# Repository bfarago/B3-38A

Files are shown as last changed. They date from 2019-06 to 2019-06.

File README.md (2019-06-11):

# B3-38A
B3-38A or V3-38A Russian Millivoltmeter

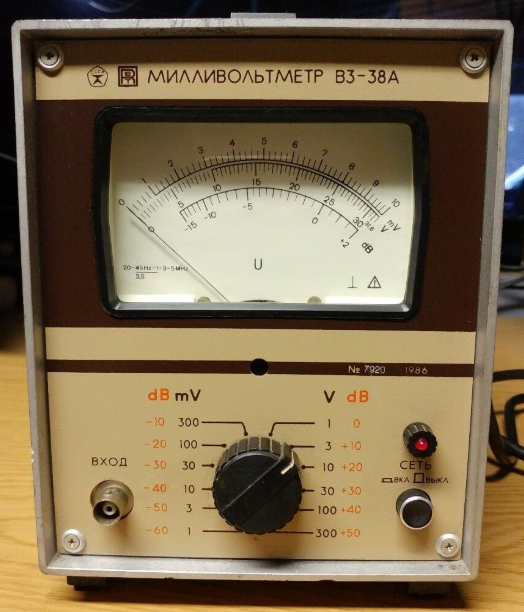
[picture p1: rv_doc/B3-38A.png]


REVERSE ENGINEERING
-------------------
This repository contains all the collected informations regarding the old russian millivoltmeter instrument. The goal to collect datasheets, schematics, etc.

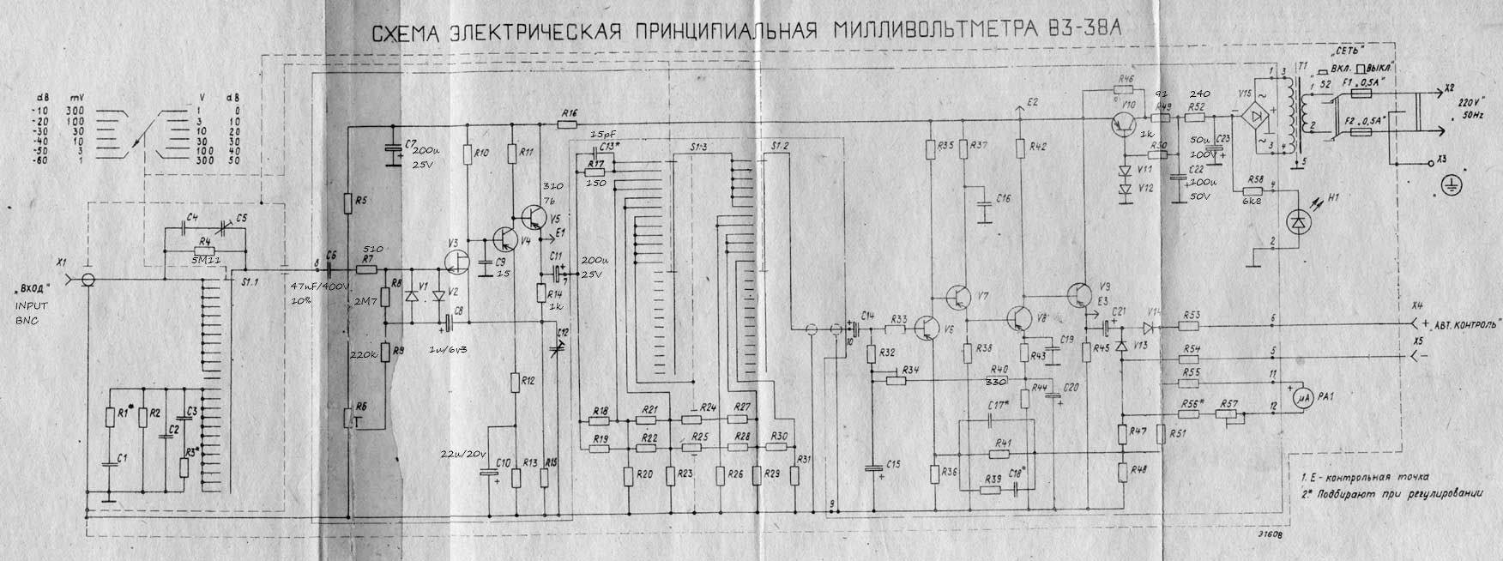
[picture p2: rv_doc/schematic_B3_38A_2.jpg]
Schematic


[BOM](rv_doc/bom.md), [Service Manual](rv_doc/B3-38A.pdf)

Technical characteristics
-------------------------
Millivoltmeter V3-38A (V3 38A, V338A, b3-38a, b338a, b3 38a)

Designed to measure the rms AC voltage sine wave of 0.1 mV to 300 V in the frequency range from 20 Hz to 5 MHz.
The span value of 1 mV, 3mV, 10mV, 30mV, 100mV, 300mV, 1V, 3V, 10V, 30V, 100V and 300V
The basic error of ± 2,5%

Millivoltmeter V3-38A is designed to measure the rms AC voltage sine wave of 0.1 mV to 300 V in the frequency range from 20 Hz to 5 MHz.
The operating conditions of use of the instrument Millivoltmeter V3-38A: ambient temperature from 10 ° to 35 ° C;
relative humidity. air 80% at 25 ° C, atmospheric pressure from 86 to 106 kPa (650 to 800 mm Hg. st.) mains (220 ± 22), frequency (50 ± 0,5) Hz .
Technical Data is a
Measurement range of the instrument voltages from 300V to 100mkV overlapping ranges with upper limits of 1 mV, 3mV, 10mV, 30mV, 100mV, 300mV, 1V, 3V, 10V, 30V, 100V and 300V. Instrument measures the voltage in the frequency range from 20 Hz to 5 MHz .
The range of frequencies of the device Millivoltmeter V3-38A has a working range of frequencies:
I from 45 Hz to 1 MHz (on);
II from 20 to 45 Hz (except);
III St.. 1 to 3 MHz (on);
IV St.. 3 to 5 MHz (inclusive).
Frequency of calibration of 1 kHz. Primary instrument error, expressed as a percentage of the upper limit established by sub-band measurements, no more than ± 2,5%.
Instrument error Millivoltmeter V3-38A in the working frequency regions, expressed as a percentage of the upper limit of the established sub-band, and the change of readings within the operating frequency ranges with respect to the frequency of calibration readings in percent, do not exceed the values shown in Table. 1.

Table 1: The limits of permissible errors (beyond the assumed changes of reading),%

| Subranges | I.: 45Hz- 1 MHz | II.: 20 - 45 Hz | III.:  1 - 3 MHz | IV.: 3 - 5 MHz |
| --- | --- | --- | --- | --- |
| 1 mV-300mV | ± 2,5 % | ± 4,0 (± 4,0) % | ± 4,0 (± 4,0) % | ± 6,0 (± 6,0) % |
| 1V-300V | ± 2,5 % | ± 4,0 (± 4,0) % | ± 6,0 (± 6,0) % | ± 6,0 (± 6,0) % |

Change readings, caused by changes in temperature. Ambient air from the normal to any temperature within the operating temperature range does not exceed the basic error for every 10 ° C change in temperature.
Change readings Millivoltmeter V3-38A, expressed as a percentage of the upper limit established by sub-band, rejecting the shape of the measured voltage from the sinusoidal (THD less than 20%) is less than half the value of the harmonic content in percent.
The deviation of the index from scratch, due to the intrinsic noise does not exceed 5% of the upper limit established by sub-band measurements with closed-circuit input.
The device retains its specifications within the rules, if its input DC voltage is not more than 250-V
Response time the device is less than 4 seconds.
Millivoltmeter V3-38A save tons of basic error handling five times after exposure to stress, but not more than 600 V.
Active impedance device, measured at a frequency of 45 Hz, less than 5 megohms at subbands upper limits 1-300mV and at least 4 Mohms subbands upper limits in 1-300
Input capacitance unit is not more than 25 pF subbands upper limits of 1-300 mV and not more than 15 pF subbands upper limits of 1-300 W.
The capacity of each of the connecting cable is not more than 80 pF. Warm-up time 15 min. Millivoltmeter V3-38A retains its specifications when powered from the mains AC voltage (220 ± 22) V (50 ± 0,5) Hz.
The power consumed by the network at a nominal voltage not exceeding 6 VA. Device allows continuous operation in the working conditions for 8 hours

Unit weight Millivoltmeter V3-38A or less than 3.2 kg.

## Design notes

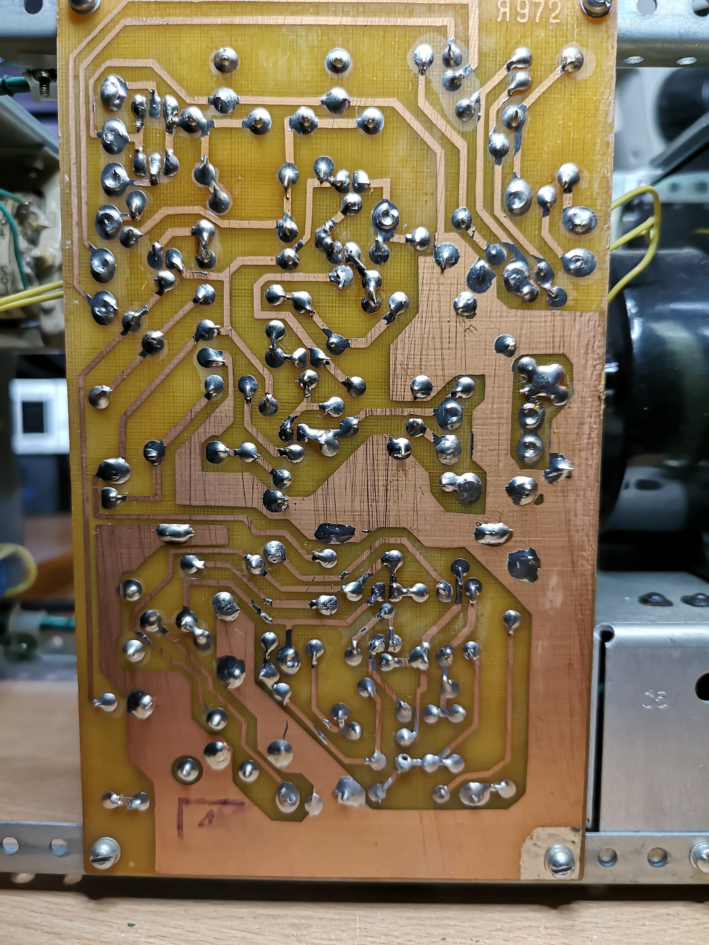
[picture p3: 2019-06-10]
rv_doc/pcb_b_JA972.jpg

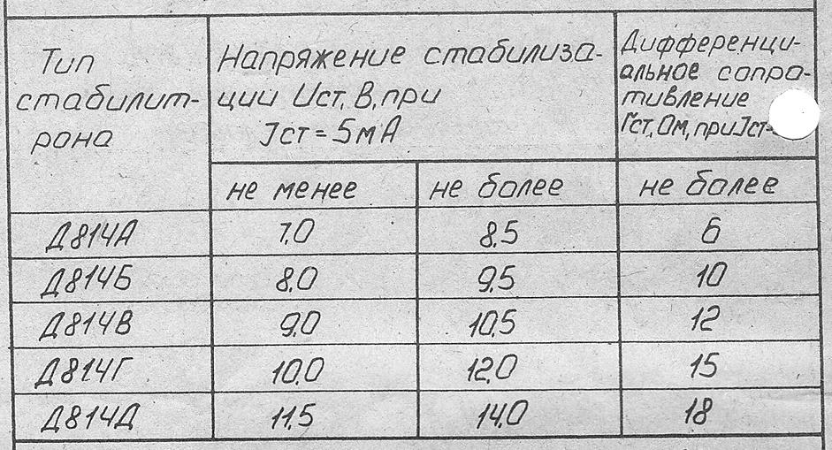
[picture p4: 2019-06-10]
rv_doc/zener_D814D.png

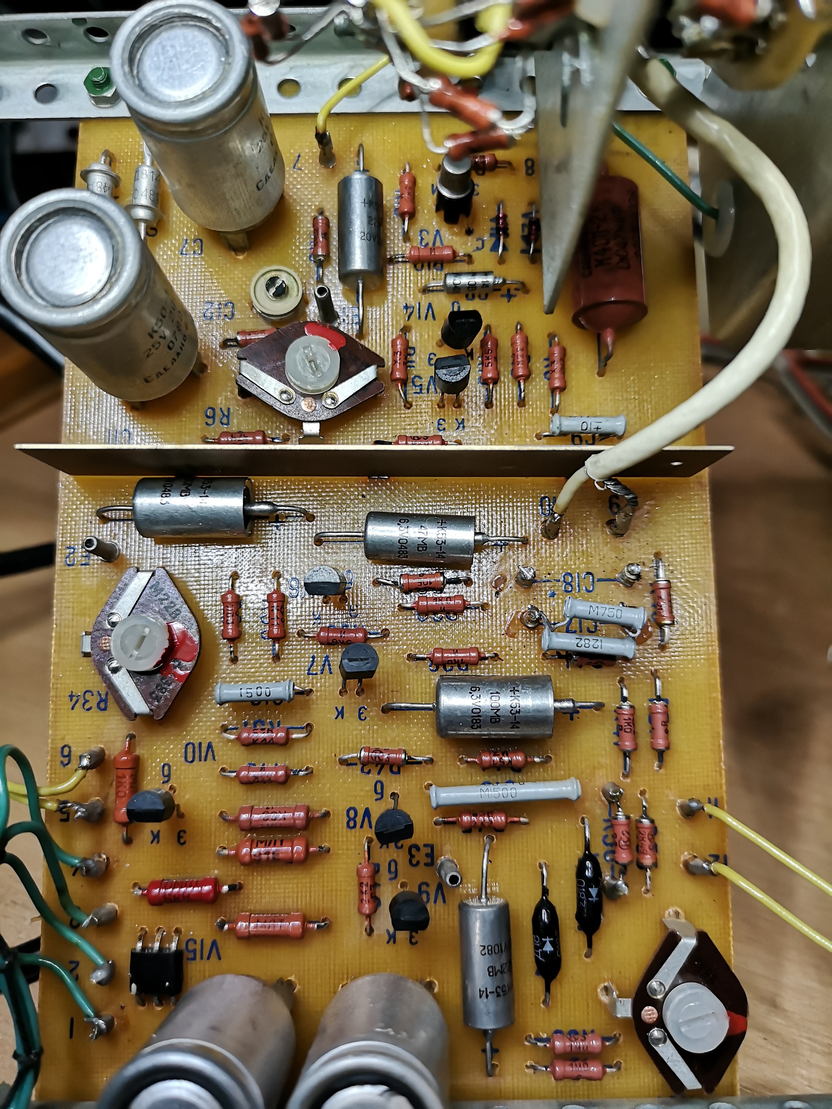
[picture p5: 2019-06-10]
rv_doc/pcb_p_JA972.jpg

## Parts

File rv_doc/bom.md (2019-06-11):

Bill of materials

| Pos | Description | Param |
| --- | --- | --- |
| C1 | KT-1-M1500-150 nF±10%-3 | 150nF ±10% |
| C2 | CrM-3-500B-r-2700n | 2700nF ±10% 500V |
| C3 | Cm-3-500B-r-l600 nF±5% | 1600nF ±5% 500V |
| C4 | KA-26-M75-3.9 nF ±10% 3 | 3,9nF ±10% |
| C5 | KF1K-MH-2/7 nF | 2nF |
| C6 | K40Í1-26 0.047 mkF ±I0% | 47nF ±10% |
| C7 | K50-12-25 B - 200 mkF | 200uF 25V |
| C8 | K53-14-6.3 B-4.7mkF±20% | 4,7uF ±20% 6,3V |
| C9 | KT-1-M47-15 nO ± 5% -3 | 15nF ±5% |
| C10 | K53-14-20 B 22 uMF±20% | 22uF ±20% 20V |
| C11 | K50-12-25 B 200 mkF | 200uF 25V |
| C12 | KT4-23 5/20 | 5nF 20V |
| C13* | KT-1M47-15 15nF l0%-3(0..27 nF) | 15nF |
| C14 | K53-14-6.3 B-47 mkF ±20%  | 47uF 6,3V ±20% |
| C15 | K53-14-6.3 B-100 ukF±20% | 100uF 6,3V ±20% |
| C16 | K10-7B-H30 1500 nF±20% | 1500nF 7V |
| C17* | KT-1-Ml 500-270 nF ±10% -3 (150..270 nF) | 270nF |
| C18* | KT-1-M47-27 nF ±10% -3 (0..47nF)| 27nF  |
| C19 | KT-l-M 1500-560 nF ±l0%-3 | 560nF |
| C20 | K53-I4-6.3 B-100 mkF±20% | 100uF 6,3V |
| C21 | K53-14-20 B-22 mkF±20% | 22uF 20V |
| C22 | K50-12-50 B-100 mkF | 100uF 50V |
| C23 | K50-12-100 B-50 mkO | 50uF 100V |

| Pos | Description | Param |
| --- | --- | --- |
| V1,2 | KD 522 B | 1N4148 |
| V3 | [Kp103L](kp103l.pdf) | p-jFET |
| V4,5,6,7 | KT 3107 B | pnp |
| V9 | KT 3107 A | pnp |
| V10 | KT 3107 B | pnp |
| V11,12 | D 814 D | zener 12V |
| V13,14 |  | diode |

| Pos | Description | Param |
| --- | --- | --- |
| R1* | MJlT-0,25-7,5 kOm±10% | 5.6-27 kOhm |
| R2 | C2-29B-0.25-5,ll kOhm±0.25% — 1,0-B | 5.11 kOhm |
| R3 | 02-10-0,25-21,8 Ohm±1%(20..22,9 Ohm) | 21,8 Ohm |
| R4 | C2-29B-1-5,11 MOhm ±0.25%- 5,0 -5 | 5,11 MOhm |
| R5 | MJ1T-025-47kOhm ±10% | 47kOhm |
| R6 | Gri3^U-33kOhm-1 | 33kOhm |

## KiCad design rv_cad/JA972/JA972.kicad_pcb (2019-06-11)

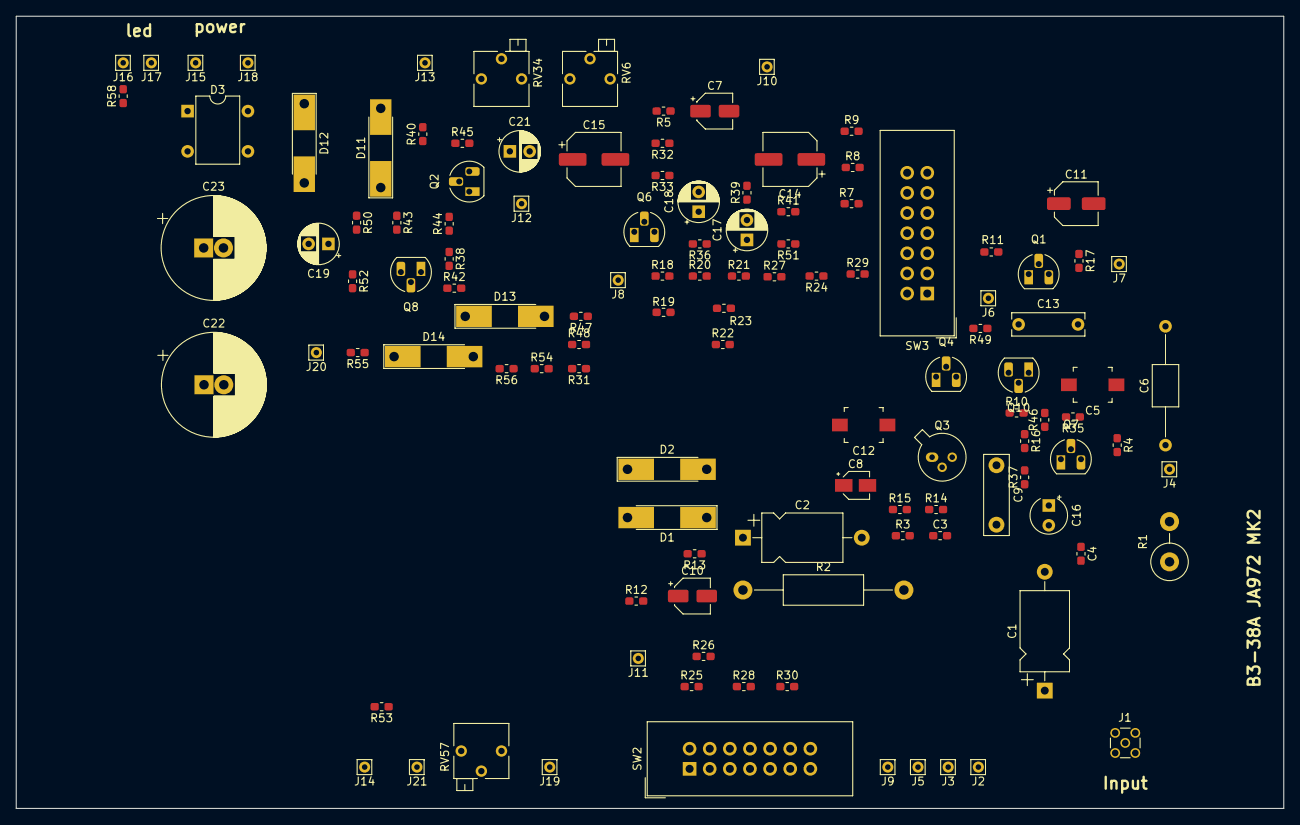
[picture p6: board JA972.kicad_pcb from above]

Board: 2 copper layers, 160.0 x 100.0 mm, 118 parts (0 on the bottom side), 61 nets, no tracks yet.

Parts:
C1: 1600 500V 5%; CP_Axial_L10.0mm_D6.0mm_P15.00mm_Horizontal
C2: 2700 500V 5%; CP_Axial_L10.0mm_D6.0mm_P15.00mm_Horizontal
C3: 150 10%; C_0603_1608Metric_Pad1.05x0.95mm_HandSolder
C4: 2p2; C_0603_1608Metric_Pad1.05x0.95mm_HandSolder
C5: 2/7; C_Trimmer_Murata_TZB4-B
C6: 0,047uF/400V/10%; C_Axial_L5.1mm_D3.1mm_P15.00mm_Horizontal
C7: 200u/25V; CP_Elec_4x5.4
C8: 1u/6v3; CP_Elec_3x5.3
C9: 15+-10%/ M47; C_Rect_L10.0mm_W3.0mm_P7.50mm_FKS3_FKP3
C10: 22u/20v; CP_Elec_4x5.8
C11: 200u/25v; CP_Elec_5x5.8
C12: CTRIM; C_Trimmer_Murata_TZB4-B
C13: 15+-10%/ M47; C_Rect_L9.0mm_W2.7mm_P7.50mm_MKT
C14: 200u/25v; CP_Elec_6.3x5.4_Nichicon
C15: 100u/6v3; CP_Elec_6.3x5.4_Nichicon
C16: x; CP_Radial_Tantal_D4.5mm_P2.50mm
C17, C18, C19: x; CP_Radial_D5.0mm_P2.50mm
C21: 200u/25v; CP_Radial_D5.0mm_P2.50mm
C22: 100u/50v; CP_Radial_D13.0mm_P2.50mm
C23: 50u/100v; CP_Radial_D13.0mm_P2.50mm
D1, D2, D13, D14: KD522B; D_MELF-RM10_Universal_Handsoldering
D3: D_Bridge_+-AA; Diode_Bridge_DIP-4_W7.62mm_P5.08mm
D11, D12: 12V; D_MELF-RM10_Universal_Handsoldering
J1: Conn_Coaxial; MMCX_Molex_73415-1471_Vertical
J2: PGM_SWITCH1; Pin_D0.7mm_L6.5mm_W1.8mm_FlatFork
J3, J5: PGM_SWITCH2; Pin_D0.7mm_L6.5mm_W1.8mm_FlatFork
J4: PGM_SWITCH3; Pin_D0.7mm_L6.5mm_W1.8mm_FlatFork
J6: E1; Pin_D0.7mm_L6.5mm_W1.8mm_FlatFork
J7, J8: P7; Pin_D0.7mm_L6.5mm_W1.8mm_FlatFork
J9, J10: P10; Pin_D0.7mm_L6.5mm_W1.8mm_FlatFork
J11: P11; Pin_D0.7mm_L6.5mm_W1.8mm_FlatFork
J12: E2; Pin_D0.7mm_L6.5mm_W1.8mm_FlatFork
J13: E3; Pin_D0.7mm_L6.5mm_W1.8mm_FlatFork
J14: P6; Pin_D0.7mm_L6.5mm_W1.8mm_FlatFork
J15: P2; Pin_D0.7mm_L6.5mm_W1.8mm_FlatFork
J16: P4; Pin_D0.7mm_L6.5mm_W1.8mm_FlatFork
J17: P1; Pin_D0.7mm_L6.5mm_W1.8mm_FlatFork
J18: P3; Pin_D0.7mm_L6.5mm_W1.8mm_FlatFork
J19, J20, J21: P5; Pin_D0.7mm_L6.5mm_W1.8mm_FlatFork
Q1, Q2, Q4, Q6, Q7, Q8, Q10: 3107B; TO-92_HandSolder
Q3: kp103l; TO-18-3
R1: 7k5; R_Axial_DIN0414_L11.9mm_D4.5mm_P5.08mm_Vertical
R2: 5k11; R_Axial_DIN0411_L9.9mm_D3.6mm_P20.32mm_Horizontal
R3: 21,8; R_0603_1608Metric_Pad1.05x0.95mm_HandSolder
R4: 5M11; R_0603_1608Metric_Pad1.05x0.95mm_HandSolder
R5: 47k; R_0603_1608Metric_Pad1.05x0.95mm_HandSolder
R7, R44: 510; R_0603_1608Metric_Pad1.05x0.95mm_HandSolder
R8: 2M7; R_0603_1608Metric_Pad1.05x0.95mm_HandSolder
R9: 220k; R_0603_1608Metric_Pad1.05x0.95mm_HandSolder
R10, R35: 5k6; R_0603_1608Metric_Pad1.05x0.95mm_HandSolder
R11, R13: 3k; R_0603_1608Metric_Pad1.05x0.95mm_HandSolder
R12: 51; R_0603_1608Metric_Pad1.05x0.95mm_HandSolder
R14, R38, R39, R47, R50, R51: 1k; R_0603_1608Metric_Pad1.05x0.95mm_HandSolder
R15: 402; R_0603_1608Metric_Pad1.05x0.95mm_HandSolder
R16: 390; R_0603_1608Metric_Pad1.05x0.95mm_HandSolder
R17: 150; R_0603_1608Metric_Pad1.05x0.95mm_HandSolder
R18, R21, R24, R27: 56k; R_0603_1608Metric_Pad1.05x0.95mm_HandSolder
R19, R22, R25, R28, R30: 357; R_0603_1608Metric_Pad1.05x0.95mm_HandSolder
R20, R23, R26, R29, R52: 240; R_0603_1608Metric_Pad1.05x0.95mm_HandSolder
R31: 165; R_0603_1608Metric_Pad1.05x0.95mm_HandSolder
R32: 22k; R_0603_1608Metric_Pad1.05x0.95mm_HandSolder
R33, R37: 110; R_0603_1608Metric_Pad1.05x0.95mm_HandSolder
R36: 10; R_0603_1608Metric_Pad1.05x0.95mm_HandSolder
R40: 33k; R_0603_1608Metric_Pad1.05x0.95mm_HandSolder
R41: 100; R_0603_1608Metric_Pad1.05x0.95mm_HandSolder
R42, R45: 2k2; R_0603_1608Metric_Pad1.05x0.95mm_HandSolder
R43: 15; R_0603_1608Metric_Pad1.05x0.95mm_HandSolder
R46: 680; R_0603_1608Metric_Pad1.05x0.95mm_HandSolder
R48: 55,6; R_0603_1608Metric_Pad1.05x0.95mm_HandSolder
R49: 91; R_0603_1608Metric_Pad1.05x0.95mm_HandSolder
R53, R54: 1M; R_0603_1608Metric_Pad1.05x0.95mm_HandSolder
R55, R56: 2,49k; R_0603_1608Metric_Pad1.05x0.95mm_HandSolder
R58: 6k8; R_0603_1608Metric_Pad1.05x0.95mm_HandSolder
RV6: 33k; Potentiometer_Bourns_3266P_Horizontal
RV34: 220k; Potentiometer_Bourns_3266P_Horizontal
RV57: 1k5; Potentiometer_Bourns_3266P_Horizontal
SW2, SW3: SW_Rotary12; IDC-Header_2x07_P2.54mm_Vertical

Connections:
/P7: C11.2, C13.2, J7.1, J8.1, R17.1, R18.1, R19.1
/P8: C5.1, C6.1, J3.1, J5.1, R4.1
/PE2: J12.1, Q2.1, Q10.3, R16.2, R35.2, R37.2, R42.2, R46.1
GNDA: C1.1, C2.1, C7.2, C9.2, C10.2, C12.2, C15.1, C16.2, C19.2, C22.1, C23.1, D3.1, D12.2, J1.2, J11.1, J15.1, R2.1, R3.1, R13.1, R15.1, R20.2, R23.2, R26.2, R29.2, R31.2, R36.1, R38.1, R44.1, R45.1, R48.1, RV6.3, SW3.7, SW3.8, SW3.9, SW3.10, SW3.11, SW3.12
unnamed: C1.2, R1.1
unnamed: C2.2, C3.2, J4.1, R1.2, R2.2
unnamed: C3.1, R3.2
unnamed: C4.1, C5.2
unnamed: C4.2, J1.1, J2.1, R4.2
unnamed: C6.2, R7.2
unnamed: C7.1, Q1.1, R5.1, R10.2, R11.2, R16.1
unnamed: C8.1, D1.2, D2.1, R8.1, R9.2
unnamed: C9.1, Q3.3, Q4.2, R10.1
unnamed: C10.1, R12.1, R13.2
unnamed: C11.1, J6.1, Q1.3, R14.2
unnamed: C8.2, C12.1, Q3.1, R14.1, R15.2
unnamed: C13.1, R17.2, SW3.1, SW3.2
unnamed: C14.1, J10.1
unnamed: C14.2, R32.1, R33.1
unnamed: C15.2, R32.2, RV34.2, RV34.3
unnamed: C16.1, Q7.1, R37.1
unnamed: C17.1, C18.1, R41.2, R51.2
unnamed: C17.2, Q6.3, R36.2, R39.1, R41.1
unnamed: C18.2, R39.2
unnamed: C19.1, Q8.3, R43.2
unnamed: C21.1, D13.1, D14.2
unnamed: C21.2, J13.1, Q2.3, R45.2
unnamed: C22.2, R49.2, R50.2, R52.1
unnamed: C23.2, D3.2, R52.2, R58.1
unnamed: D1.1, D2.2, Q3.2, R7.1, R8.2
unnamed: D3.3, J17.1
unnamed: D3.4, J18.1
unnamed: D11.1, Q10.2, R50.1
unnamed: D11.2, D12.1
unnamed: D13.2, R47.2, R54.1, R56.1
unnamed: D14.1, R53.1, R55.1
unnamed: J9.1, SW2.13
unnamed: J14.1, R53.2
unnamed: J16.1, R58.2
unnamed: J19.1, R54.2
unnamed: J20.1, R55.2
unnamed: J21.1, RV57.1, RV57.2
unnamed: Q1.2, Q4.1, R11.1
unnamed: Q2.2, Q8.1, R42.1
unnamed: Q4.3, R12.2
unnamed: Q6.1, Q7.2, R35.1
unnamed: Q6.2, R33.2
unnamed: Q7.3, Q8.2, R38.2
unnamed: Q10.1, R46.2, R49.1
unnamed: R5.2, RV6.1
unnamed: R9.1, RV6.2
unnamed: R18.2, R19.2, R20.1, R21.1, R22.1, SW3.3, SW3.4
unnamed: R21.2, R22.2, R23.1, R24.1, R25.1, SW3.5, SW3.6
unnamed: R24.2, R25.2, R26.1, R27.1, R28.1, SW2.7, SW2.8
unnamed: R27.2, R28.2, R29.1, R30.1, SW2.9, SW2.10, SW2.11
unnamed: R30.2, R31.1, SW2.12
unnamed: R40.1, R43.1, R44.2
unnamed: R40.2, RV34.1
unnamed: R47.1, R48.2
unnamed: R56.2, RV57.3
unnamed: SW2.1, SW2.2, SW2.3, SW2.4, SW2.5, SW2.6, SW3.13
